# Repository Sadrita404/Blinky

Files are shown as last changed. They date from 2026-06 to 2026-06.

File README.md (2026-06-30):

bannar led

| Title | Blinky |
| :-- | :---|
|Author |Sadrita Neogi|

## Whta is this ?

It is A 555 LED chaser board — a classic beginner PCB project.

## Why I built this project ?
So this is one of the starter project in the stasis website, so when you went to this guide, I feel like that I want to make something without the SMD components only using the components that can be hand solder , so I went with this project and I learn a lot of things about the KiCad ,etc.

<div align="center">

| PCB and Schematic | |
| :---: | :---: |
|  |  |
|  |  |
|  |  |

<div align="center">
  <h2> Final Look </h2>
  <table border="0" cellpadding="10" cellspacing="0" style="border-collapse: collapse;">
    <tr>
      <!-- FRONT SIDE CARD -->
      <td align="center" valign="top" width="50%" style="background: #ffffff; border: 1px solid #d0d7de; border-radius: 12px; padding: 16px; box-shadow: 0 4px 12px rgba(0,0,0,0.05);">
        Front Side View
        <div style="margin-top: 12px; font-family: -apple-system, BlinkMacSystemFont, 'Segoe UI', Helvetica, Arial, sans-serif; font-size: 13px; color: #57606a; font-weight: 600; text-transform: uppercase; letter-spacing: 0.5px;">
          ▲ Front Side View
        </div>
      </td>
      <!-- SPACER FOR GITHUB MOBILE DEGRADATION -->
      <td width="2%">&nbsp;</td>
      <!-- BACK SIDE CARD -->
      <td align="center" valign="top" width="50%" style="background: #ffffff; border: 1px solid #d0d7de; border-radius: 12px; padding: 16px; box-shadow: 0 4px 12px rgba(0,0,0,0.05);">
        Back Side View
        <div style="margin-top: 12px; font-family: -apple-system, BlinkMacSystemFont, 'Segoe UI', Helvetica, Arial, sans-serif; font-size: 13px; color: #57606a; font-weight: 600; text-transform: uppercase; letter-spacing: 0.5px;">
          ▲ Back Side View
        </div>
      </td>
    </tr>
  </table>
</div>
</div>

<div align="center">
  <h2> Bill of Materials </h2>
</div>

| Name | Purpose | Qty | Total (USD) | Link | Distributor |
| :--- | :--- | :---: | :---: | :---: | :--- |
| Blinky Board Kit | Shipped to you - kit project | 1 | $10.00 | - | Hack Club |
| PCB (moq 5) | The Main Board | 5 | $4.00 | [Link](https://jlcpcb.com/) | JLCPCB |
| Shipping PCB	| E- Post (Cheapest) | 	- |	$9.81	| — | 	JLCPCB |
| Total | | | $23.81 | | | |

For this Project I only need the grant of $14 for the PCB and for the other parts it will provided by Hack Club ( Blinky Board Kit) as it is already selected .

**Project Under Hack Club**

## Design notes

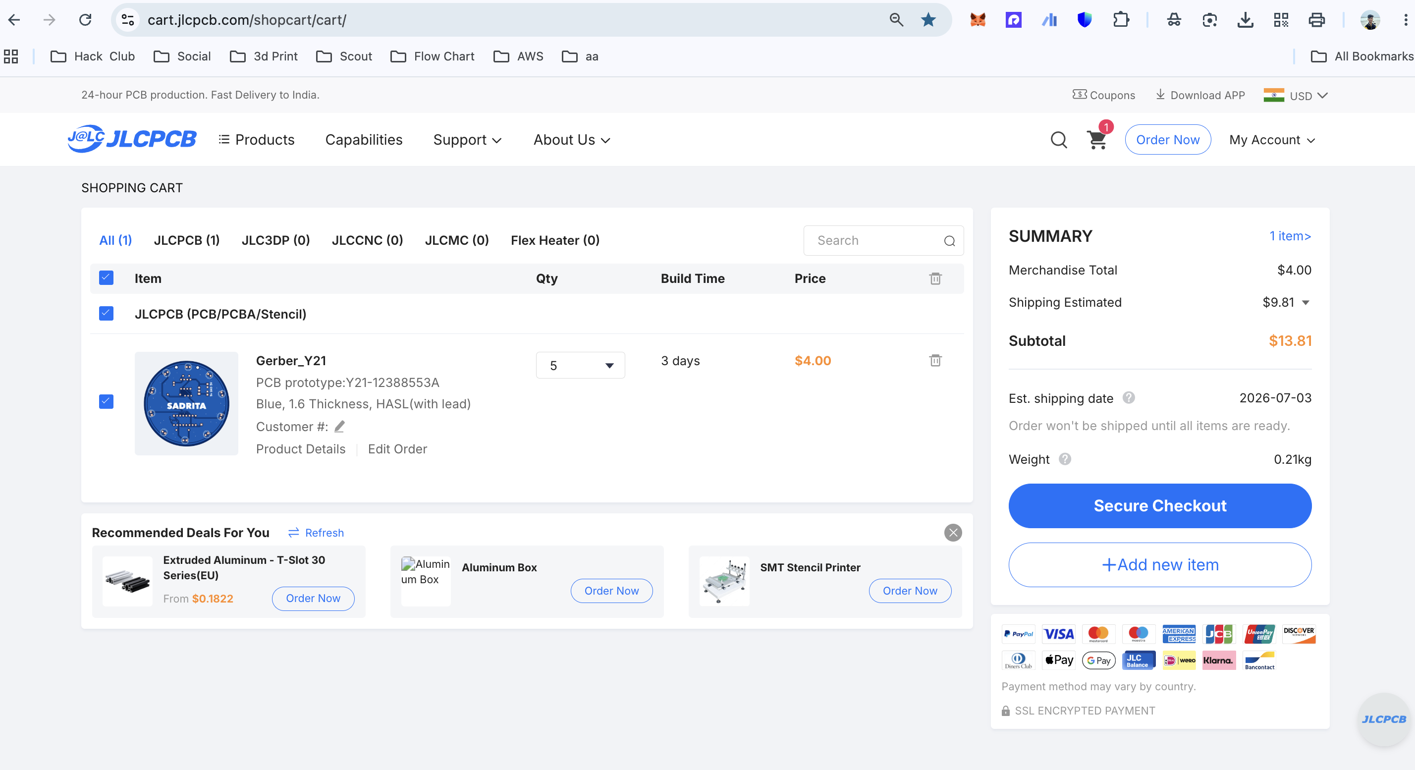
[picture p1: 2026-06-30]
Bill/bill 1.png

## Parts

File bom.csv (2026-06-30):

Name | Purpose | Quantity | Total Cost (USD) | Link | Distributor
PCB (moq 5) | The Main Board | 5 | 4.00 | https://jlcpcb.com/ | jlcpcb
Blinky Board Kit | Shipped to you - kit project | 1 | 10.00 | - | Hack Club

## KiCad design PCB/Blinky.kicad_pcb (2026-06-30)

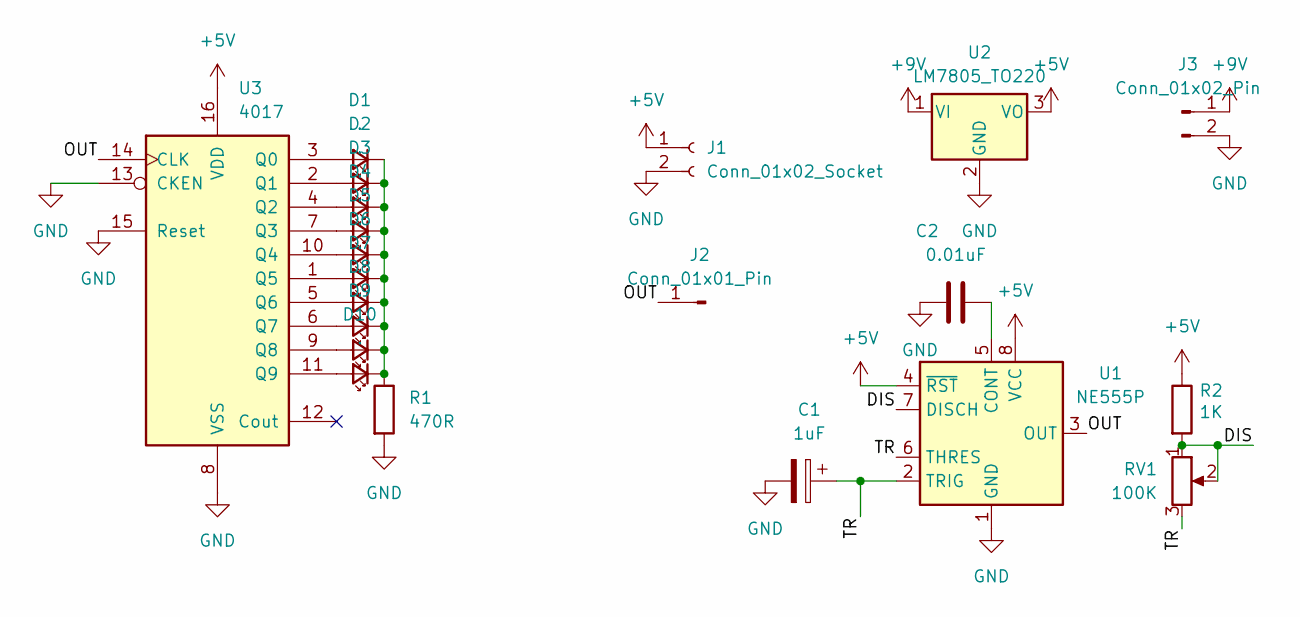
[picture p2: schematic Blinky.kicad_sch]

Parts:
C1: 1uF; CP_Radial_D5.0mm_P2.00mm
C2: 0.01uF; C_Disc_D4.3mm_W1.9mm_P5.00mm
D1, D2, D3, D4, D5, D6, D7, D8, D9, D10: .; LED_D5.0mm_FlatTop
J1: Conn_01x02_Socket; PinHeader_1x02_P2.54mm_Vertical
J2: Conn_01x01_Pin; PinHeader_1x01_P2.54mm_Vertical
J3: Conn_01x02_Pin; PinHeader_1x02_P2.54mm_Vertical
R1: 470R; R_Axial_DIN0207_L6.3mm_D2.5mm_P10.16mm_Horizontal
R2: 1K; R_Axial_DIN0207_L6.3mm_D2.5mm_P10.16mm_Horizontal
RV1: 100K; Potentiometer_Bourns_3296W_Vertical
U1: NE555P; DIP-8_W7.62mm
U2: LM7805_TO220; TO-220-3_Vertical
U3: 4017; DIP-16_W7.62mm

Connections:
+5V: J1.1, R2.1, U1.4 (~RST), U1.8 (VCC), U2.3 (VO), U3.16 (VDD)
+9V: J3.1, U2.1 (VI)
/DIS: R2.2, RV1.1, RV1.2, U1.7 (DISCH)
/OUT: J2.1 (Pin_1_1), U1.3 (OUT), U3.14 (CLK)
/TR: C1.1, RV1.3, U1.2 (TRIG), U1.6 (THRES)
GND: C1.2, C2.1, J1.2, J3.2, R1.2, U1.1 (GND), U2.2 (GND), U3.8 (VSS), U3.13 (CKEN), U3.15 (Reset)
unnamed: D1.2 (A), U3.3 (Q0)
unnamed: D1.1 (K), D2.1 (K), D3.1 (K), D4.1 (K), D5.1 (K), D6.1 (K), D7.1 (K), D8.1 (K), D9.1 (K), D10.1 (K), R1.1
unnamed: D2.2 (A), U3.2 (Q1)
unnamed: D3.2 (A), U3.4 (Q2)
unnamed: D4.2 (A), U3.7 (Q3)
unnamed: D5.2 (A), U3.10 (Q4)
unnamed: D6.2 (A), U3.1 (Q5)
unnamed: D7.2 (A), U3.5 (Q6)
unnamed: D8.2 (A), U3.6 (Q7)
unnamed: D9.2 (A), U3.9 (Q8)
unnamed: D10.2 (A), U3.11 (Q9)
unnamed: C2.2, U1.5 (CONT)

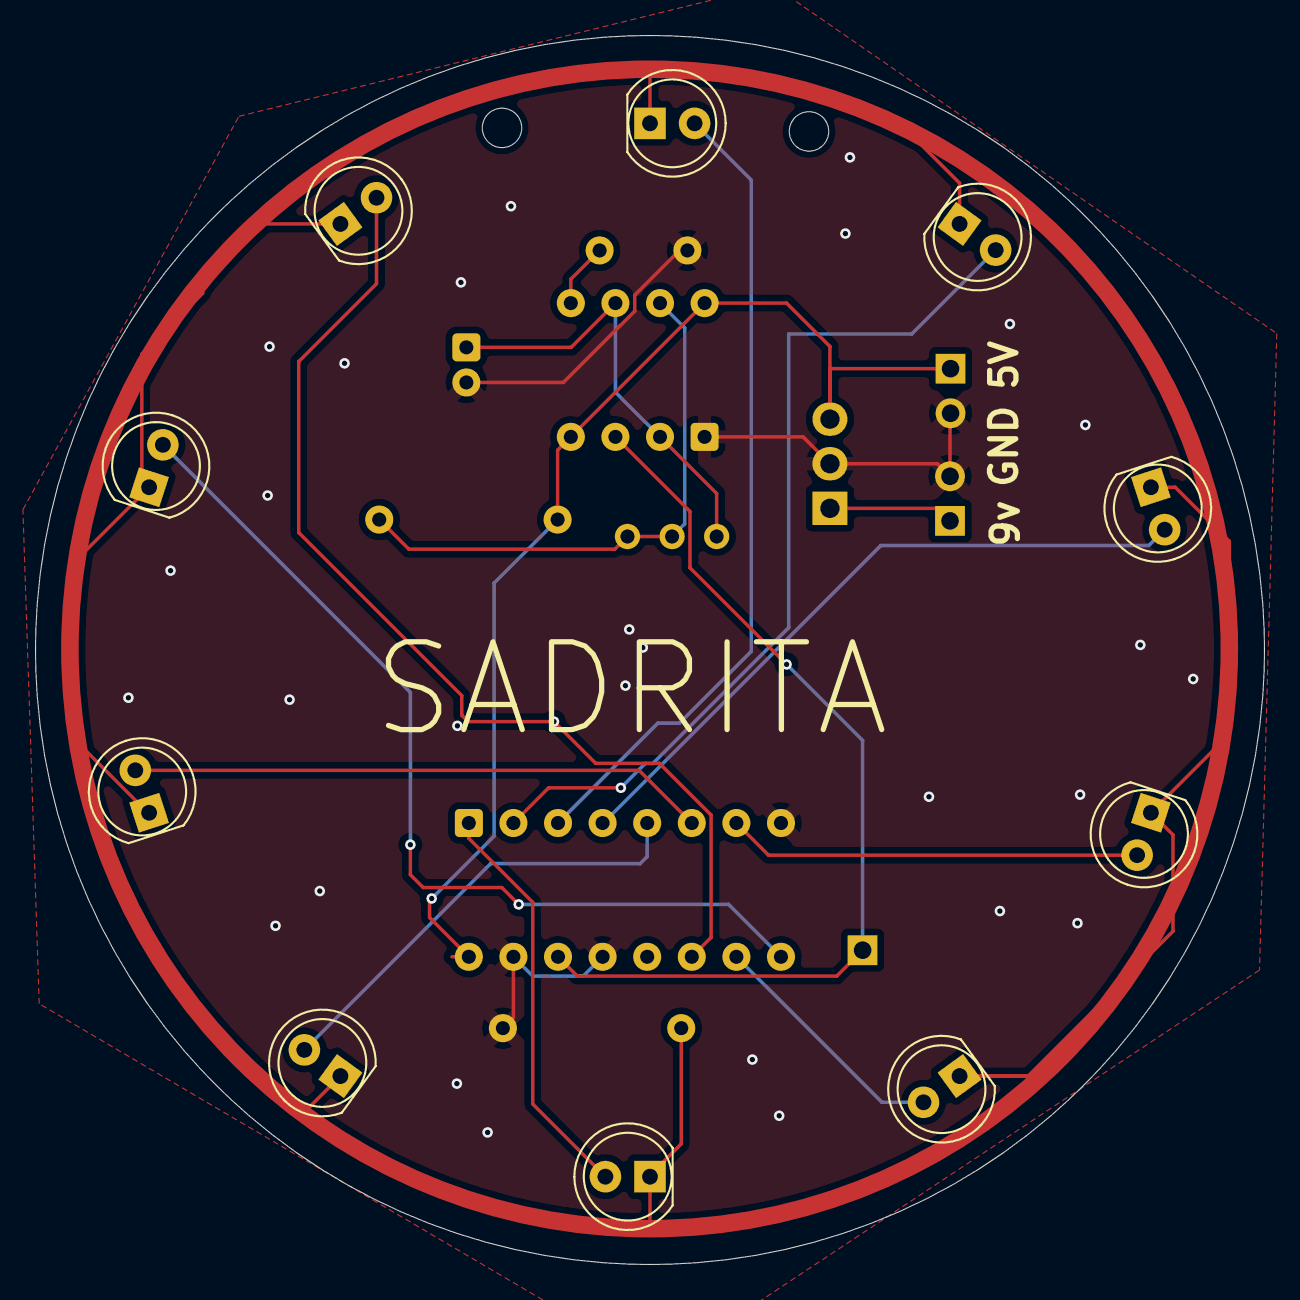
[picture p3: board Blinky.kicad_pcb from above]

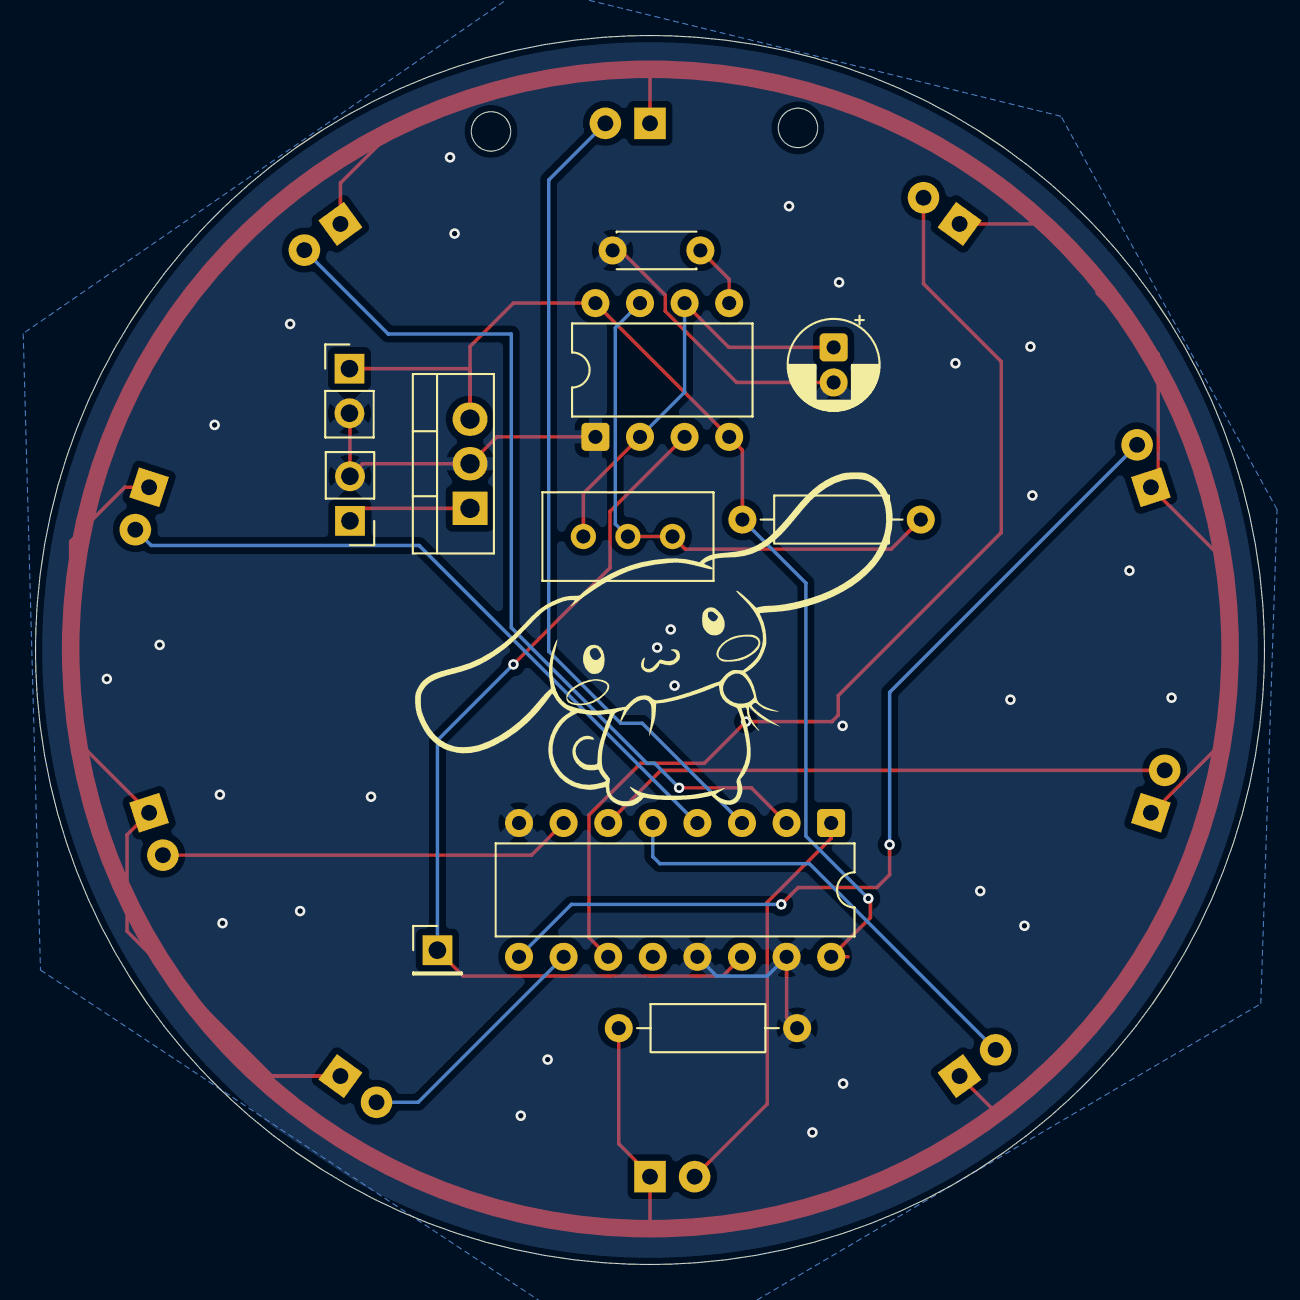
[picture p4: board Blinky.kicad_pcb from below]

Board: 2 copper layers, 70.0 x 70.0 mm, 21 parts (11 on the bottom side), 18 nets.
